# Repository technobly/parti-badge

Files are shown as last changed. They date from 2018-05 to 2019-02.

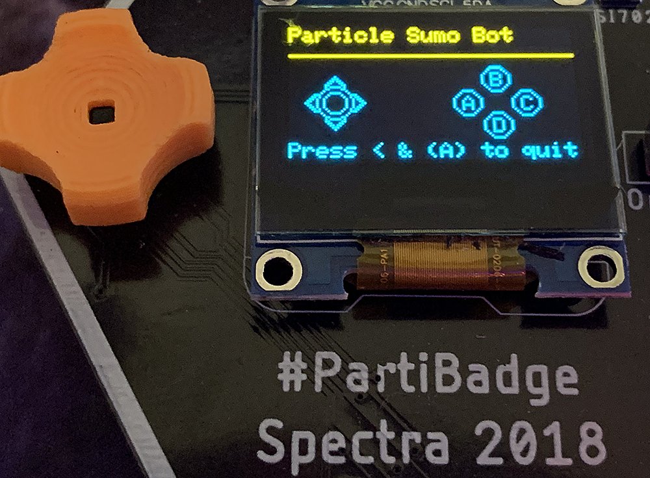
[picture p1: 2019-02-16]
images/sumo-bot-menu.png

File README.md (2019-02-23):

# #PartiBadge Sumo Bot Edition

- Fixed Particle Logo
- Sped up refresh rate of display by 400%
- Sped up boot time with SEMI_AUTOMATIC mode (runs setup() before connected to Particle Cloud) and shortened some things
- Added Sumo Bot Menu
    - Added RC Controller for [Particle Mesh Sumo Bot](https://github.com/technobly/particle-mesh-sumo-bot)
        - Try driving with the joystick and turning at the same time with buttons for smooth figure 8's!
    - Added Logo Turtle OS control system
        - Enter a string of commands `F` `B` `L` `R` and press `>` to send to the Sumo Bot.
        - Use `^` and `v` to adjust the default Command Delay of 500 ms (100 ~ 1000 ms).
- Left rest of PartiBadge functionality in-tact

## Local Compile

```
$ git checkout v0.9.0
$ cd firmware/main
// enter DFU mode
firmware/main $ make clean all -s APPDIR=~/code/debugging/technobly/parti-badge/firmware PLATFORM=xenon COMPILE_LTO=n program-dfu
```



(original README.md follows)

---

# #PartiBadge

The #PartiBadge is a Wi-Fi connected, full-featured, Particle-powered conference badge. Because who want to wear a piece of plastic around their neck when they can wear a PCB?

The #PartiBadge was designed by the Particle team and is currently used as an interactive learning platform for conferences and other developer events.

For workshop hands-on labs and other details, click [here](https://part.cl/workshop).

The hardware folder contains Eagle design files for iterations of the badge hardware. Since the original creation of the Electron-based PartiBadge in the Spring of 2018, there have been two additional major iterations to support the Photon (v2) and Mesh-based hardware (v3).

The firmware folder contains firmware for the latest version of the badge, currently v3.

The finished badge includes:

1.  A 1" OLED Screen
2.  An SMD Piezo buzzer
3.  A SPDT Switch
4.  A 5-way joystick
5.  An SMD Si7021 temperature and Humidity sensor
6.  4 Tactile LED Buttons in Red, Blue, Green and Yellow/Orange
7.  An I2C-Compatible breakout for #BadgeLife add-ons

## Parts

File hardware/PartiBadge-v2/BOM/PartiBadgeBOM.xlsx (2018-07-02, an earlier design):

Part Desc | Footprint names | Reference Part # | Ordered From | Per Badge Cost | # Needed for Badge
SMD 4.7K OHM 1% 1/10W 1206 Resistor | R10 |  | Digi-Key |  | 100
SMD 2.2k OHM 1% 1/16W 1206 Resistor | R5, R6 |  | Digi-Key |  | 200
SMD 200 OHM 5% 1/4W 0805 Resistor | R7 |  | Digi-Key |  | 100
SMD 100 OHM 0.1% 1/4W 1206 | R9 |  | Digi-Key |  | 100
SMD 200 OHM 0.1% 1/4W 1206 | R1, R3, R4 |  | Digi-Key |  | 300
SMD 33 OHM 0.5% 1W 1206 | R2 |  | Digi-Key |  | 100
0.1uF 25V 0603 Ceramic Capacitor | C1 |  | Digi-Key |  | 100
4.7UF 10V X7S 0603 Ceramic Capacitor | C2 |  | Digi-Key |  | 100
Silicon Labs SI7021-A20-IM HU/Temp Sensor 3.6V I2C 3% 6DFN | SI7021 | 336-3142-5-ND (https://www.digikey.com/product-detail/en/silicon-labs/SI7021-A20-IM/336-3142-5-ND/5048937) | Digi-Key |  | 100
Murata Electronics AUDIO PIEZO TRANSDUCER 12.5V SMD (PKMCS0909E4000-R1) | PIEZO | 490-9647-1-ND (https://www.digikey.com/product-detail/en/murata-electronics-north-america/PKMCS0909E4000-R1/490-9647-1-ND/4878401) | Digi-Key |  | 100
E-Switch SWITCH SLIDE SPDT 200MA 30V | S5 | EG1903-ND (https://www.digikey.com/product-detail/en/e-switch/EG1218/EG1903-ND/101726) | Digi-Key |  | 100
LED Tactile Button - Green | GREEN | COM-10440 (https://www.sparkfun.com/products/10440) | Sparkfun |  | 100
LED Tactile Button - Orange | YELLOW | COM-10441 (https://www.sparkfun.com/products/10441) | Sparkfun |  | 100
LED Tactile Button - Red | RED | COM-10442 (https://www.sparkfun.com/products/10442) | Sparkfun |  | 100
LED Tactile Button - Blue | BLUE | COM-10443 (https://www.sparkfun.com/products/10443) | Sparkfun |  | 100
5-way Tactile Switch | JOYSTICK | COM-10063 (https://www.sparkfun.com/products/10063) | Sparkfun |  | 100
Vishay Semiconductor TSMP IR Detector | IC2 | TSMP58000-ND (https://www.digikey.com/product-detail/en/vishay-semiconductor-opto-division/TSMP58000/TSMP58000-ND/4073588) | Digi-Key |  | 100
WorldChips 0.96" OLED Display | U$5 | SSD1306 (https://www.aliexpress.com/item/0-96-inch-IIC-Serial-Yellow-Blue-OLED-Display-Module-128X64-I2C-SSD1306-12864-LCD-Screen/32828449458.html) | AliExpress |  | 100
LiiToKala Li-On 3.7v 3400mAh Battery |  | 18650 (https://www.aliexpress.com/item/6PCS-2017-Original-LiitoKala-18650-3400mAh-NCR18650B-3400-battery-3-7V-Li-ion-Rechargebale-battery-PCB/32824482157.html) | AliExpress |  | 100
Keystone Electronics 1042 Battery Clip | U1 | 36-1042-ND (https://www.digikey.com/product-detail/en/keystone-electronics/1042/36-1042-ND/2745668) | Digi-Key |  | 100
Pololu 5V Step-Up Voltage Regulator U3V12F5 | IC1 | 2115 (https://www.pololu.com/product/2115) | Pololu |  | 100
12 Position Female Header | Photon Headers | S6100-ND (https://www.digikey.com/product-detail/en/sullins-connector-solutions/PPTC121LFBN-RC/S6100-ND/807231) | Digi-Key |  | 200
Badge BOM Total

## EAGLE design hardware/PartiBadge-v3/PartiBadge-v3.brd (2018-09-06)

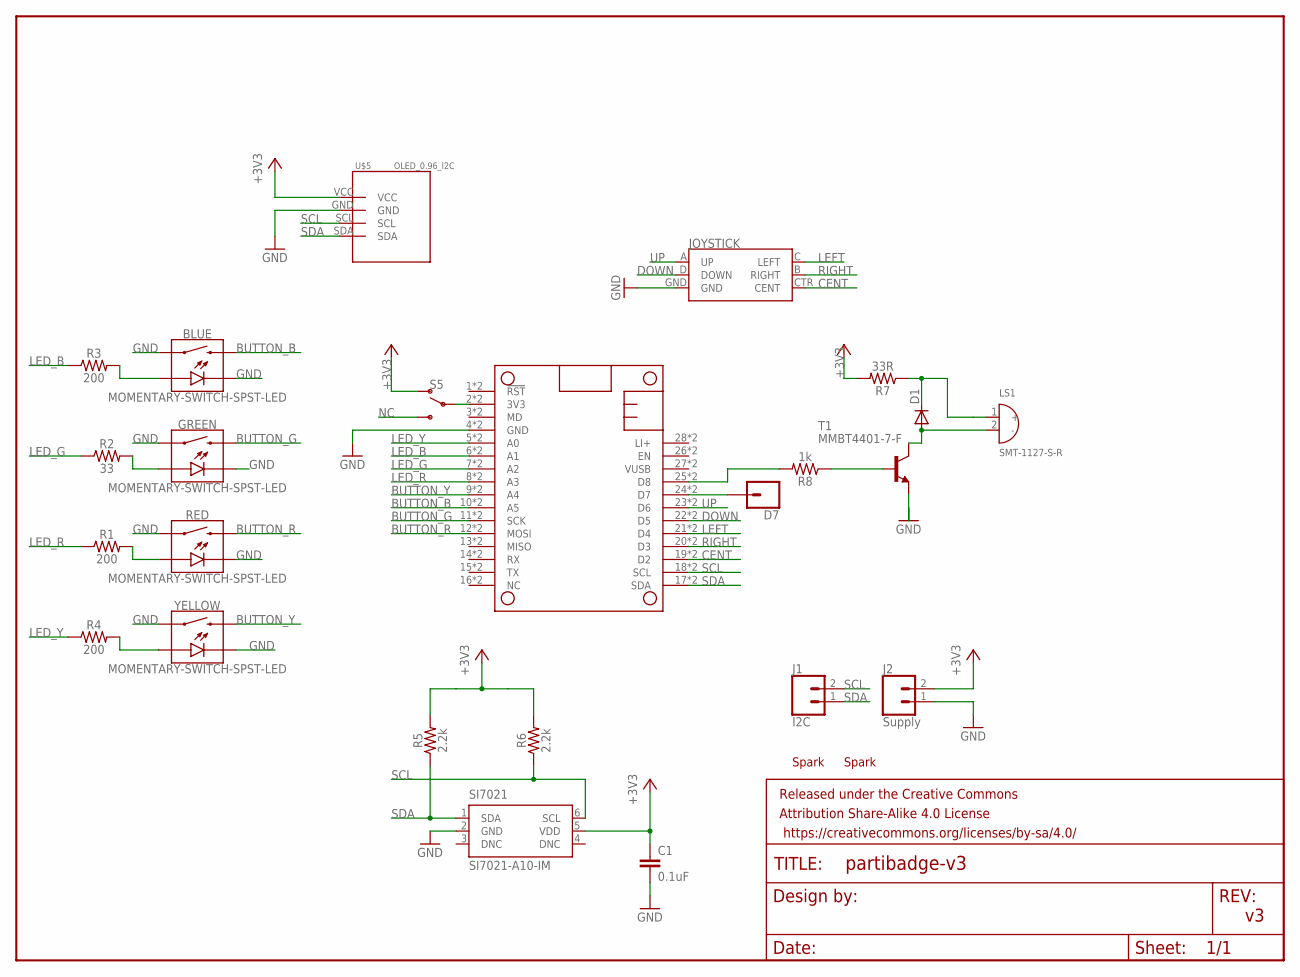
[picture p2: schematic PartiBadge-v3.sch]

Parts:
BLUE: MOMENTARY-SWITCH-SPST-LED; TACTILE_SWITCH_LED_PTH_12MM_KIT
C1: 0.1uF; 0603
D1: DIODE-SOD323-W; SOD323-W
D7: CONN_01; 1X01
GREEN: MOMENTARY-SWITCH-SPST-LED; TACTILE_SWITCH_LED_PTH_12MM_KIT
J1: I2C; 1X02
J2: Supply; 1X02
JOYSTICK: JOYSTICK_MINI
LS1: SMT-1127-S-R; XDCR_SMT-1127-S-R
MS1: PARTICLE_MESH_SMTDUAL; FEATHERWING_SMT2
PARTIFRAME: FRAME-LETTERNO_PACKAGE; DUMMY
R1, R3, R4: 200; 1206
R2: 33; 1206
R5, R6: 2.2k; 0603
R7: 33R; 0603
R8: 1k; 0603
RED: MOMENTARY-SWITCH-SPST-LED; TACTILE_SWITCH_LED_PTH_12MM_KIT
S5: SWITCH-SPDT-PTH-11.6X4.0MM; SWITCH_SPDT_PTH_11.6X4.0MM
SI7021: SI7021-A10-IM; DFN6-3X3
T1: MMBT4401-7-F; SOT23-BEC
U$1, U$2: SPARK_LOGO_WITH_PLANE; SPARK_LOGO_PLUS_PLANE
U$5: OLED_0.96_I2C
YELLOW: MOMENTARY-SWITCH-SPST-LED; TACTILE_SWITCH_LED_PTH_12MM_KIT

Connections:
3V3: MS1.2 (3V3), MS1.2' (3V3), S5.2
+3V3: C1.1, J2.2, R5.2, R6.2, R7.2, S5.1 (O), SI7021.5 (VDD), U$5.VCC
BUTTON_B: BLUE.2, MS1.10 (A5), MS1.10' (A5)
BUTTON_G: GREEN.2, MS1.11 (SCK), MS1.11' (SCK)
BUTTON_R: MS1.12 (MOSI), MS1.12' (MOSI), RED.2
BUTTON_Y: MS1.9 (A4), MS1.9' (A4), YELLOW.2
CENT: JOYSTICK.CTR (CENT), MS1.19 (D2), MS1.19' (D2)
DOWN: JOYSTICK.D (DOWN), MS1.22 (D5), MS1.22' (D5)
GND: BLUE.4 (1), BLUE.C, C1.2, GREEN.4 (1), GREEN.C, J2.1, JOYSTICK.GND, MS1.4 (GND), MS1.4' (GND), RED.4 (1), RED.C, SI7021.2 (GND), T1.E, U$5.GND, YELLOW.4 (1), YELLOW.C
LED_B: MS1.6 (A1), MS1.6' (A1), R3.1
LED_G: MS1.7 (A2), MS1.7' (A2), R2.1
LED_R: MS1.8 (A3), MS1.8' (A3), R1.1
LED_Y: MS1.5 (A0), MS1.5' (A0), R4.1
LEFT: JOYSTICK.C (LEFT), MS1.21 (D4), MS1.21' (D4)
unnamed: D7.1, MS1.24 (D7), MS1.24' (D7)
unnamed: MS1.25 (D8), MS1.25' (D8), R8.2
unnamed: R1.2, RED.A
unnamed: R8.1, T1.B
unnamed: GREEN.A, R2.2
unnamed: BLUE.A, R3.2
unnamed: R4.2, YELLOW.A
unnamed: D1.A, LS1.2 (-), T1.C
unnamed: D1.C, LS1.1 (+), R7.1
NC: S5.3 (S)
RIGHT: JOYSTICK.B (RIGHT), MS1.20 (D3), MS1.20' (D3)
SCL: J1.2, MS1.18 (SCL), MS1.18' (SCL), R6.1, SI7021.6 (SCL), U$5.SCL
SDA: J1.1, MS1.17 (SDA), MS1.17' (SDA), R5.1, SI7021.1 (SDA), U$5.SDA
UP: JOYSTICK.A (UP), MS1.23 (D6), MS1.23' (D6)

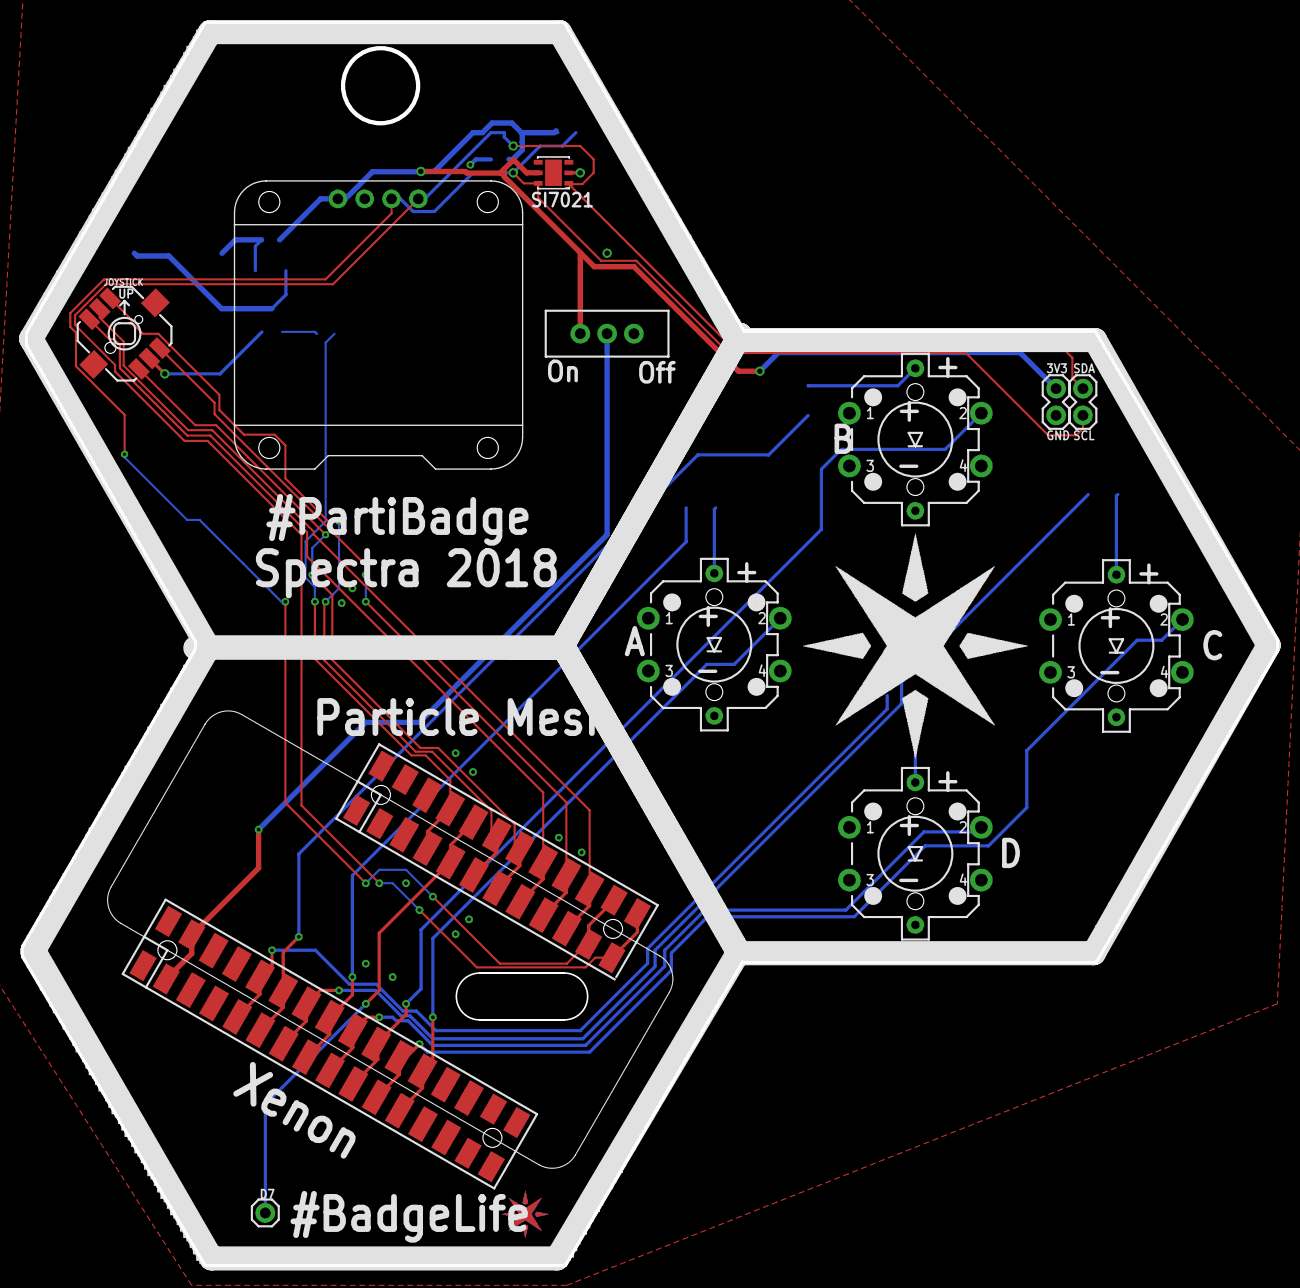
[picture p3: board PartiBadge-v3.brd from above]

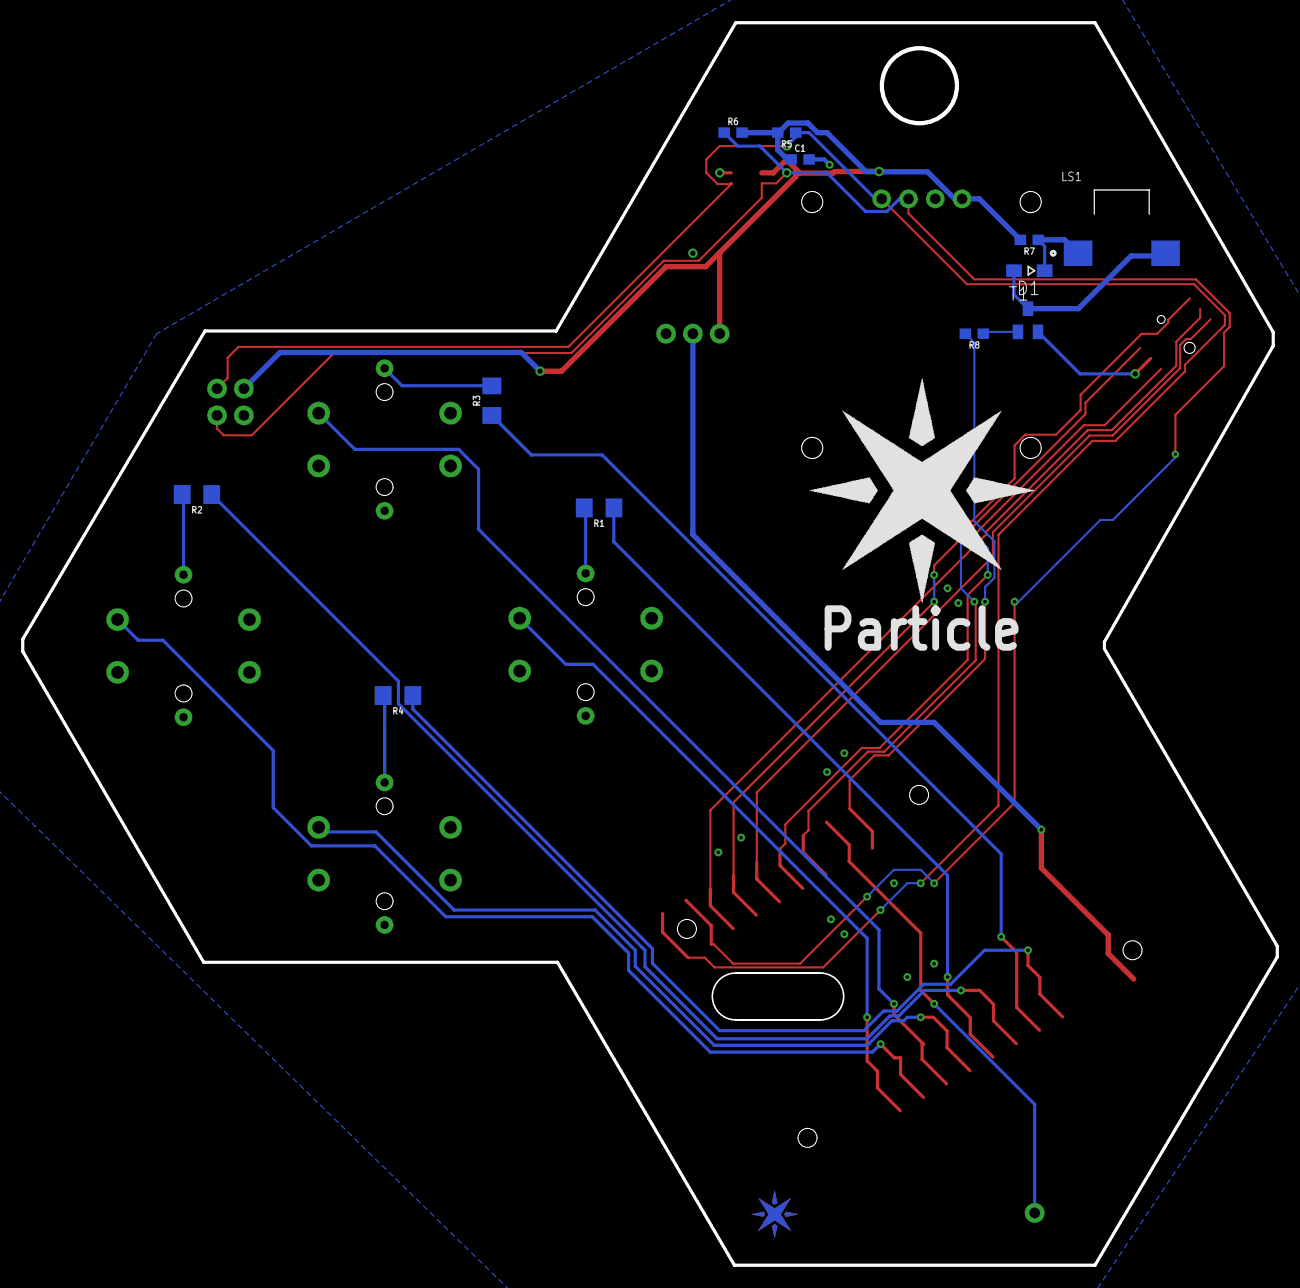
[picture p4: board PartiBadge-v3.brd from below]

Board: 4 copper layers, 118.9 x 117.7 mm, 30 parts (15 on the bottom side), 27 nets.

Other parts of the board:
U$3: MESH#1PX#SVG
U$4, U$6: SPARK-LOGO

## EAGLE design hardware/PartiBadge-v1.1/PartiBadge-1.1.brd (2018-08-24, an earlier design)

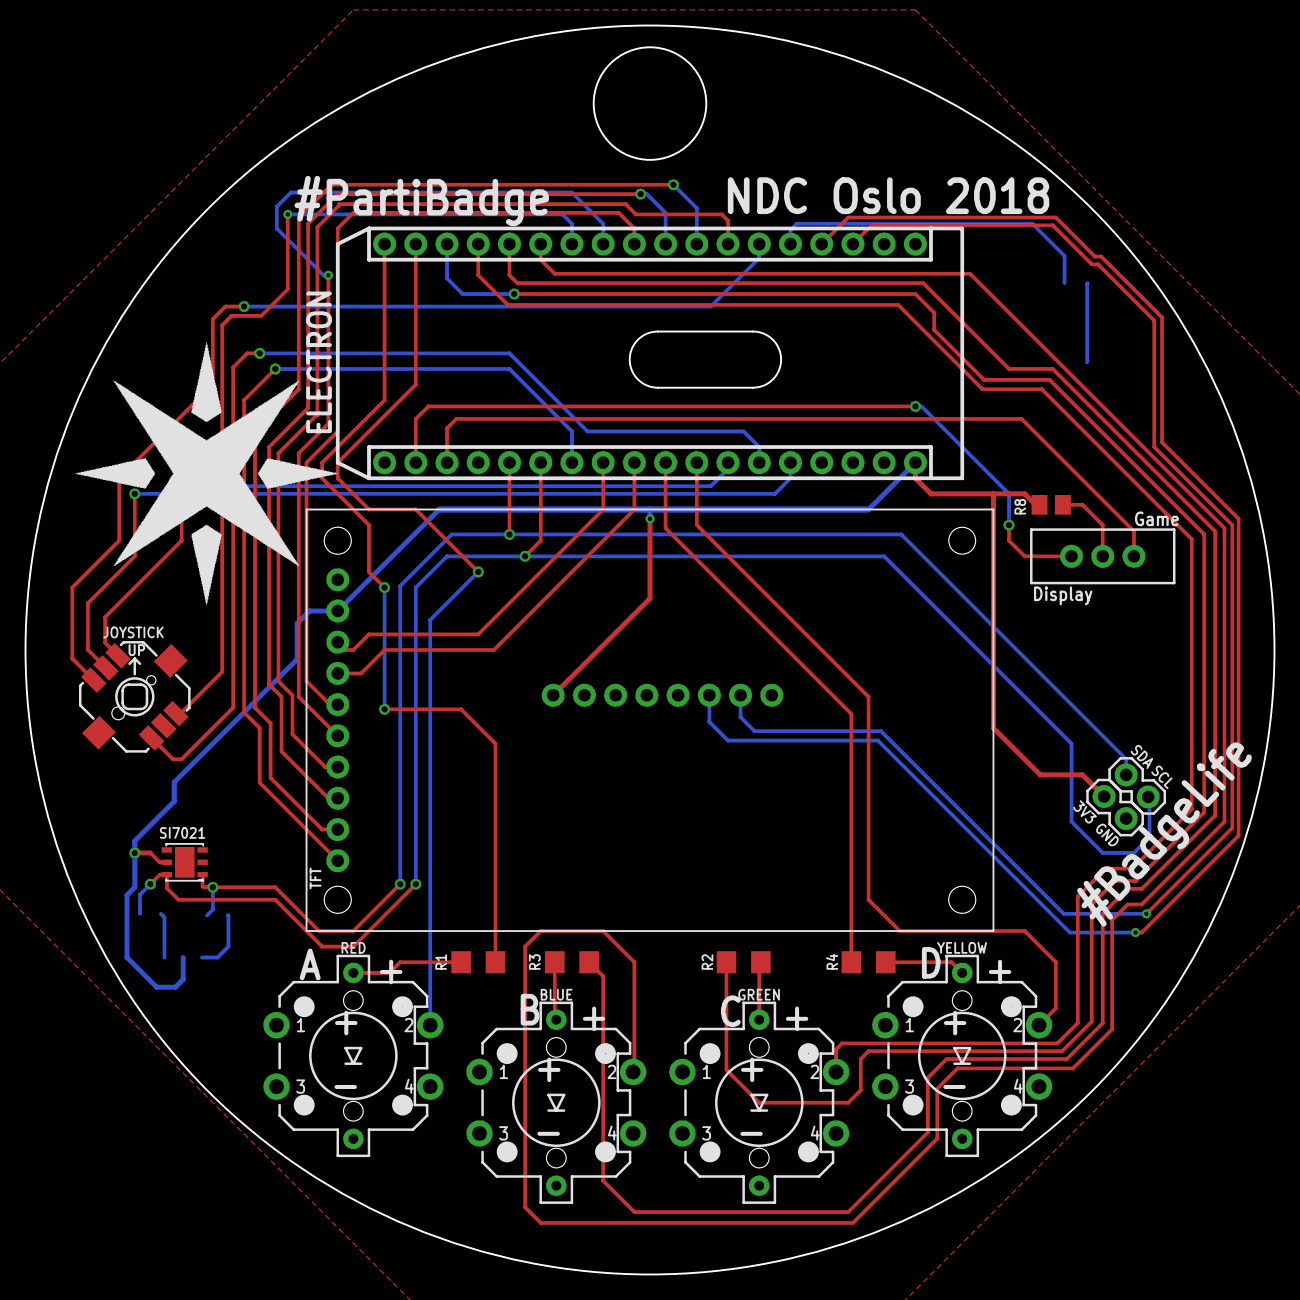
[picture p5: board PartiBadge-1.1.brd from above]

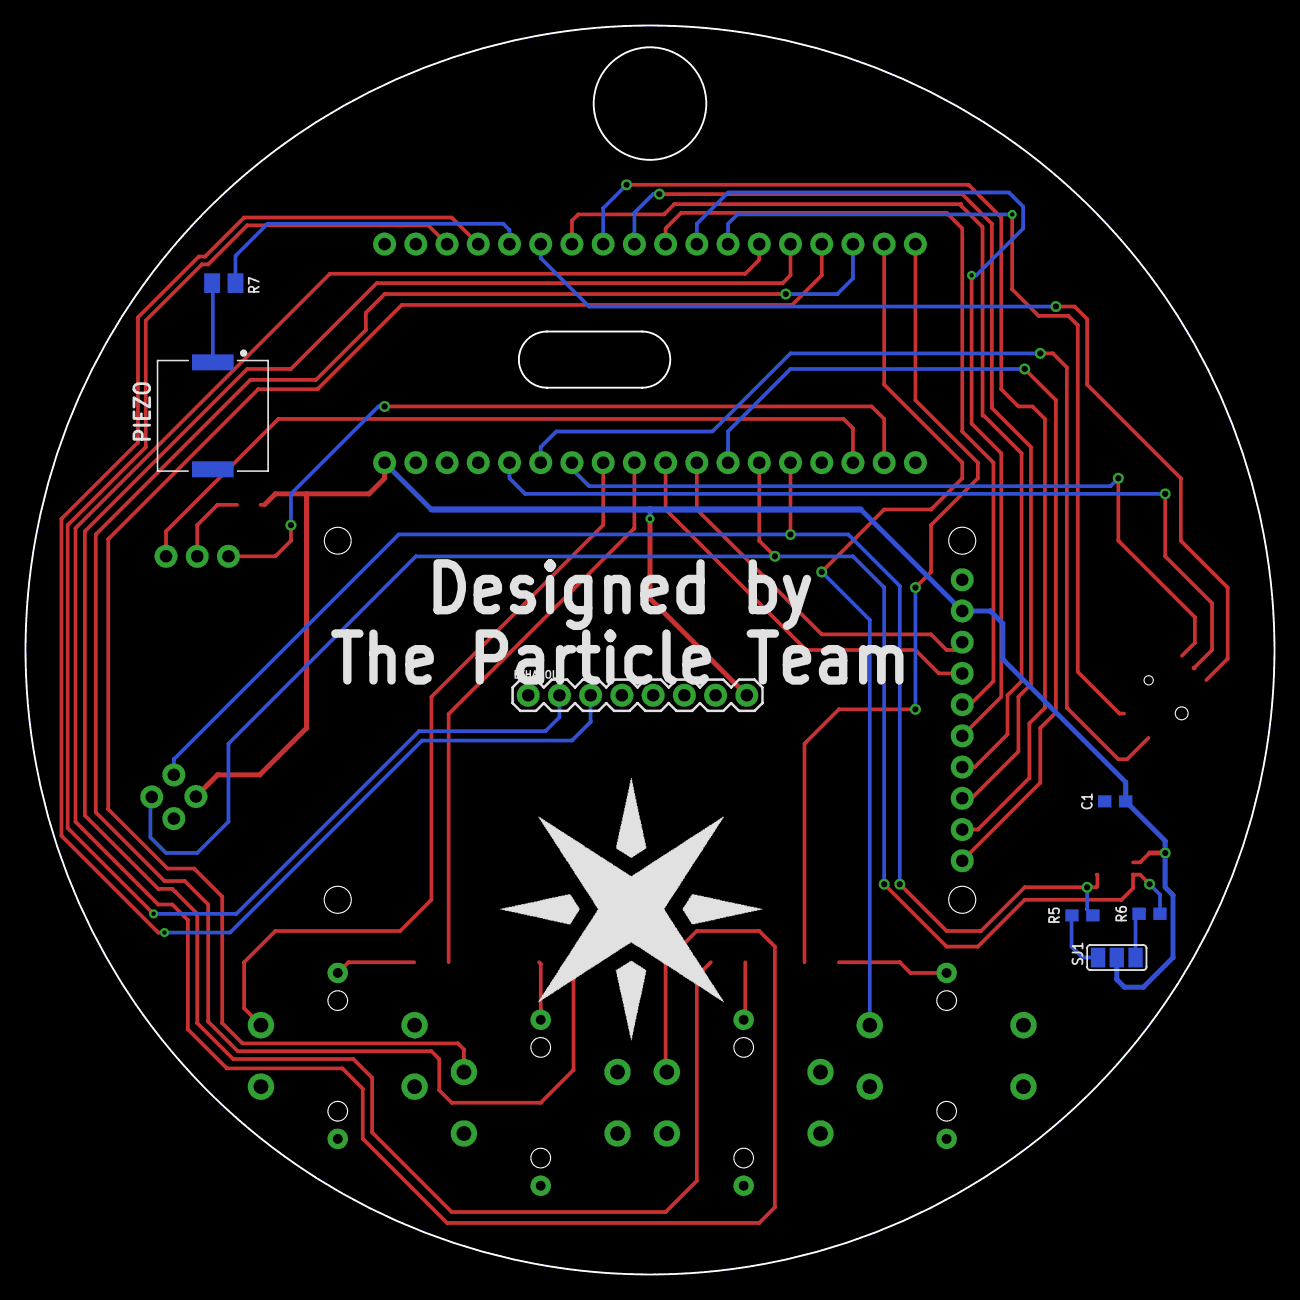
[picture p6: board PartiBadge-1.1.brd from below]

Board: 4 copper layers, 101.6 x 101.6 mm, 28 parts (8 on the bottom side), 38 nets.

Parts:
BLUE: MOMENTARY-SWITCH-SPST-LED; TACTILE_SWITCH_LED_PTH_12MM_KIT
C1: 0.1uF; 0603
DRILEGEND: DRILEGEND
ELECTRON: ELECTRON_WITH_HEADERS; ELECTRON
ETHANOL: 1X08
GREEN: MOMENTARY-SWITCH-SPST-LED; TACTILE_SWITCH_LED_PTH_12MM_KIT
J1: I2C; 1X02
J2: Supply; 1X02
JOYSTICK: JOYSTICK_MINI
PARTIFRAME: FRAME-LETTERNO_PACKAGE; DUMMY
PIEZO: PKMCS0909E4000-R1; XDCR_PKMCS0909E4000-R1
R1, R2, R3, R4: 200; 1206
R5, R6: 4.7k; 0603
R7, R8: 100; M0805
RED: MOMENTARY-SWITCH-SPST-LED; TACTILE_SWITCH_LED_PTH_12MM_KIT
S5: SWITCH_SPDT_PTH_11.6X4.0MM
SI7021: SI7021-A10-IM; DFN6-3X3
SJ1: SJ_2
TFT: 1X10_NO_SILK
U$1, U$2: SPARK#PNG
U$3: FRAME_A_L
YELLOW: MOMENTARY-SWITCH-SPST-LED; TACTILE_SWITCH_LED_PTH_12MM_KIT

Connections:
3V3: C1.1, ELECTRON.36, ETHANOL.8, J2.2, R8.2, SI7021.5, SJ1.2, TFT.9
BUTTON_YELLOW: ELECTRON.29, YELLOW.2
CENT: ELECTRON.32, JOYSTICK.CTR
DOWN: ELECTRON.31, JOYSTICK.D
ELECTRON_RX: ELECTRON.4, ETHANOL.3
ELECTRON_TX: ELECTRON.3, ETHANOL.2
GND: BLUE.4, BLUE.C, C1.2, ELECTRON.2, ELECTRON.33, ETHANOL.6, GREEN.4, GREEN.C, J2.1, JOYSTICK.GND, PIEZO.2, RED.4, RED.C, SI7021.2, TFT.10, YELLOW.4, YELLOW.C
LED_BLUE: ELECTRON.14, R3.1
LED_GREEN: ELECTRON.16, R2.1
LED_RED: ELECTRON.18, R1.1
LED_YELLOW: ELECTRON.28, R4.1
LEFT: ELECTRON.6, JOYSTICK.C
unnamed: ELECTRON.5, R7.2
unnamed: ELECTRON.20, S5.1
unnamed: ELECTRON.21, S5.3
unnamed: R1.2, RED.A
unnamed: ELECTRON.17, RED.2
unnamed: ELECTRON.15, GREEN.2
unnamed: GREEN.A, R2.2
unnamed: BLUE.A, R3.2
unnamed: BLUE.2, ELECTRON.13
unnamed: R4.2, YELLOW.A
unnamed: R5.2, SJ1.3
unnamed: R6.2, SJ1.1
unnamed: PIEZO.1, R7.1
unnamed: R8.1, S5.2
RIGHT: ELECTRON.12, JOYSTICK.B
SCL: ELECTRON.24, J1.2, R6.1, SI7021.6
SDA: ELECTRON.23, J1.1, R5.1, SI7021.1
SD_CS: ELECTRON.10, TFT.6
SPI_DC: ELECTRON.27, TFT.7
SPI_MISO: ELECTRON.8, TFT.2
SPI_MOSI: ELECTRON.7, TFT.4
SPI_SCK: ELECTRON.9, TFT.3
TFT_CS: ELECTRON.11, TFT.5
TFT_LITE: ELECTRON.25, TFT.1
TFT_RST: ELECTRON.26, TFT.8
UP: ELECTRON.30, JOYSTICK.A

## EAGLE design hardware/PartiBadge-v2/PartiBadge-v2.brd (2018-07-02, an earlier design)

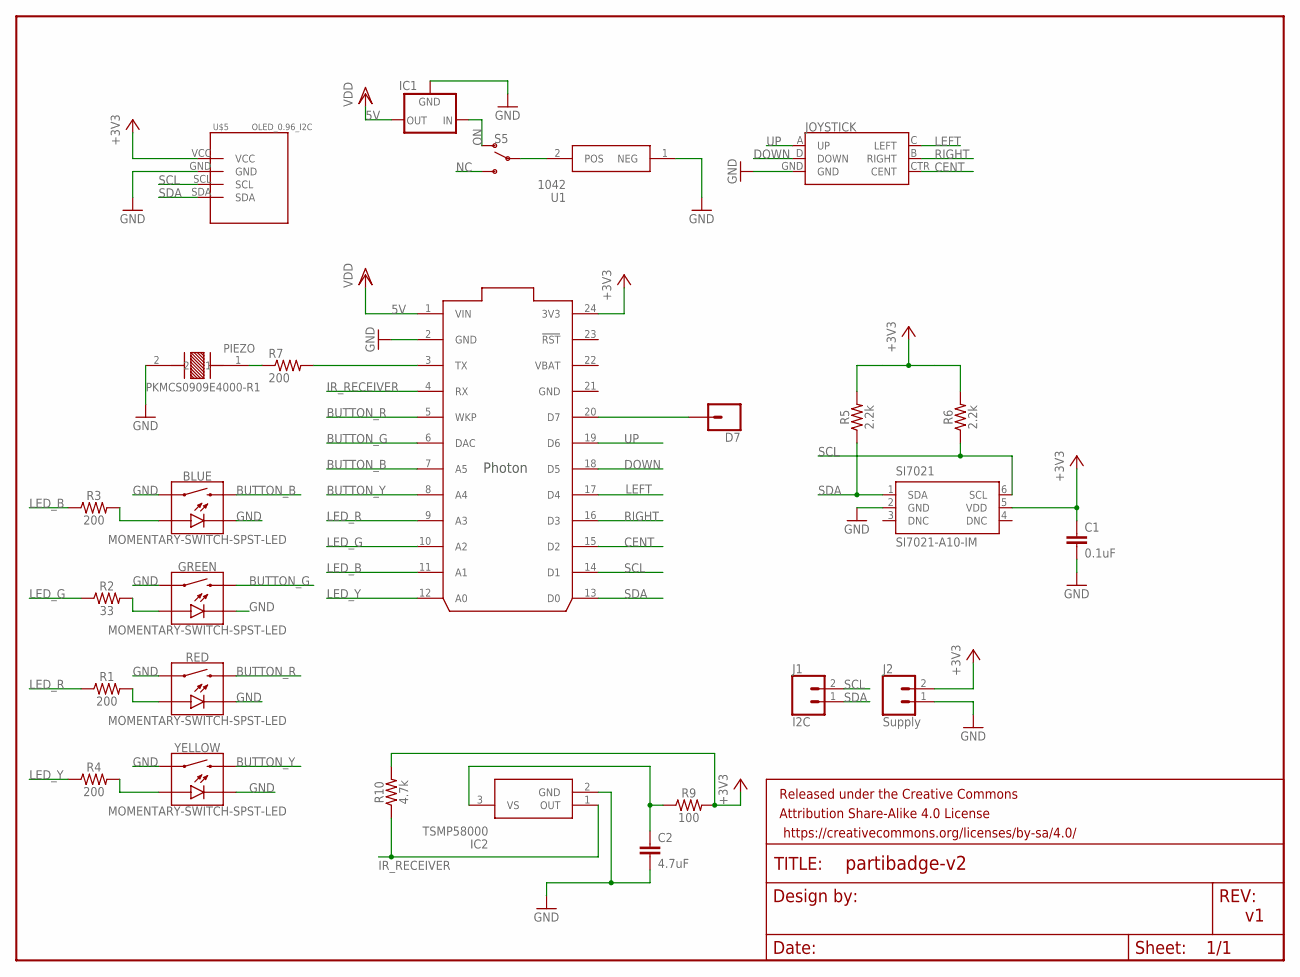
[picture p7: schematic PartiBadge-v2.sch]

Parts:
BLUE: MOMENTARY-SWITCH-SPST-LED; TACTILE_SWITCH_LED_PTH_12MM_KIT
C1: 0.1uF; 0603
C2: 4.7uF; 0603
D7: CONN_01; 1X01
GREEN: MOMENTARY-SWITCH-SPST-LED; TACTILE_SWITCH_LED_PTH_12MM_KIT
IC1: 78XXS
IC2: TSMP58000
J1: I2C; 1X02
J2: Supply; 1X02
JOYSTICK: JOYSTICK_MINI
PARTIFRAME: FRAME-LETTERNO_PACKAGE; DUMMY
PHOTON: PHOTON_WITH_HEADERS; PHOTON
PIEZO: PKMCS0909E4000-R1; XDCR_PKMCS0909E4000-R1
R1, R3, R4: 200; 1206
R2: 33; 1206
R5, R6: 2.2k; 0603
R7: 200; M0805
R9: 100; 1206
R10: 4.7k; 1206
RED: MOMENTARY-SWITCH-SPST-LED; TACTILE_SWITCH_LED_PTH_12MM_KIT
S5: SWITCH-SPDT-PTH-11.6X4.0MM; SWITCH_SPDT_PTH_11.6X4.0MM
SI7021: SI7021-A10-IM; DFN6-3X3
U1: 1042; KEYSTONE-1042
U$5: OLED_0.96_I2C
YELLOW: MOMENTARY-SWITCH-SPST-LED; TACTILE_SWITCH_LED_PTH_12MM_KIT

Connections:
5V: IC1.OUT, PHOTON.1 (VIN)
+3V3: C1.1, J2.2, PHOTON.24 (3V3), R5.2, R6.2, R9.2, R10.2, SI7021.5 (VDD), U$5.VCC
BATT: S5.2, U1.2 (POS)
BUTTON_B: BLUE.2, PHOTON.7 (A5)
BUTTON_G: GREEN.2, PHOTON.6 (DAC)
BUTTON_R: PHOTON.5 (WKP), RED.2
BUTTON_Y: PHOTON.8 (A4), YELLOW.2
CENT: JOYSTICK.CTR (CENT), PHOTON.15 (D2)
D7: D7.1, PHOTON.20 (D7)
DOWN: JOYSTICK.D (DOWN), PHOTON.18 (D5)
GND: BLUE.4 (1), BLUE.C, C1.2, C2.2, GREEN.4 (1), GREEN.C, IC1.GND, IC2.2 (GND), J2.1, JOYSTICK.GND, PHOTON.2 (GND), PHOTON.21 (GND), PIEZO.2, RED.4 (1), RED.C, SI7021.2 (GND), U1.1 (NEG), U$5.GND, YELLOW.4 (1), YELLOW.C
IR_RECEIVER: IC2.1 (OUT), PHOTON.4 (RX), R10.1
LED_B: PHOTON.11 (A1), R3.1
LED_G: PHOTON.10 (A2), R2.1
LED_R: PHOTON.9 (A3), R1.1
LED_Y: PHOTON.12 (A0), R4.1
LEFT: JOYSTICK.C (LEFT), PHOTON.17 (D4)
unnamed: PHOTON.3 (TX), R7.2
unnamed: R1.2, RED.A
unnamed: GREEN.A, R2.2
unnamed: BLUE.A, R3.2
unnamed: C2.1, IC2.3 (VS), R9.1
unnamed: R4.2, YELLOW.A
unnamed: PIEZO.1, R7.1
NC: S5.3 (S)
ON: IC1.IN, S5.1 (O)
RIGHT: JOYSTICK.B (RIGHT), PHOTON.16 (D3)
SCL: J1.2, PHOTON.14 (D1), R6.1, SI7021.6 (SCL), U$5.SCL
SDA: J1.1, PHOTON.13 (D0), R5.1, SI7021.1 (SDA), U$5.SDA
UP: JOYSTICK.A (UP), PHOTON.19 (D6)
VBAT: PHOTON.22 (VBAT)

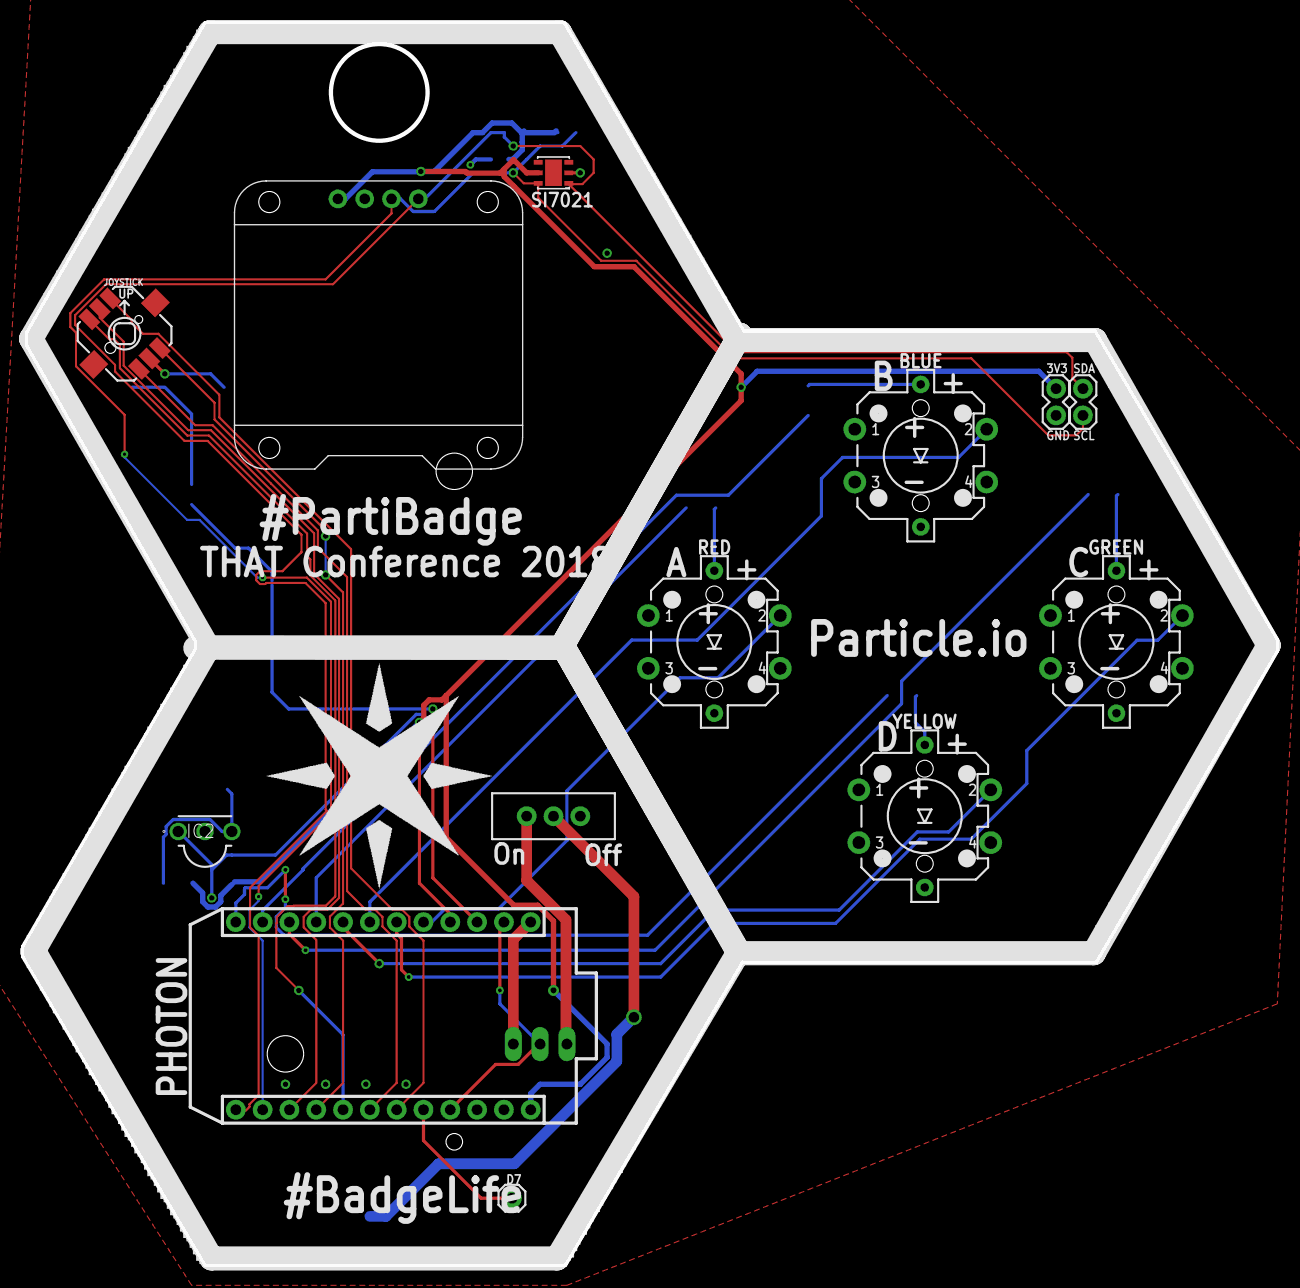
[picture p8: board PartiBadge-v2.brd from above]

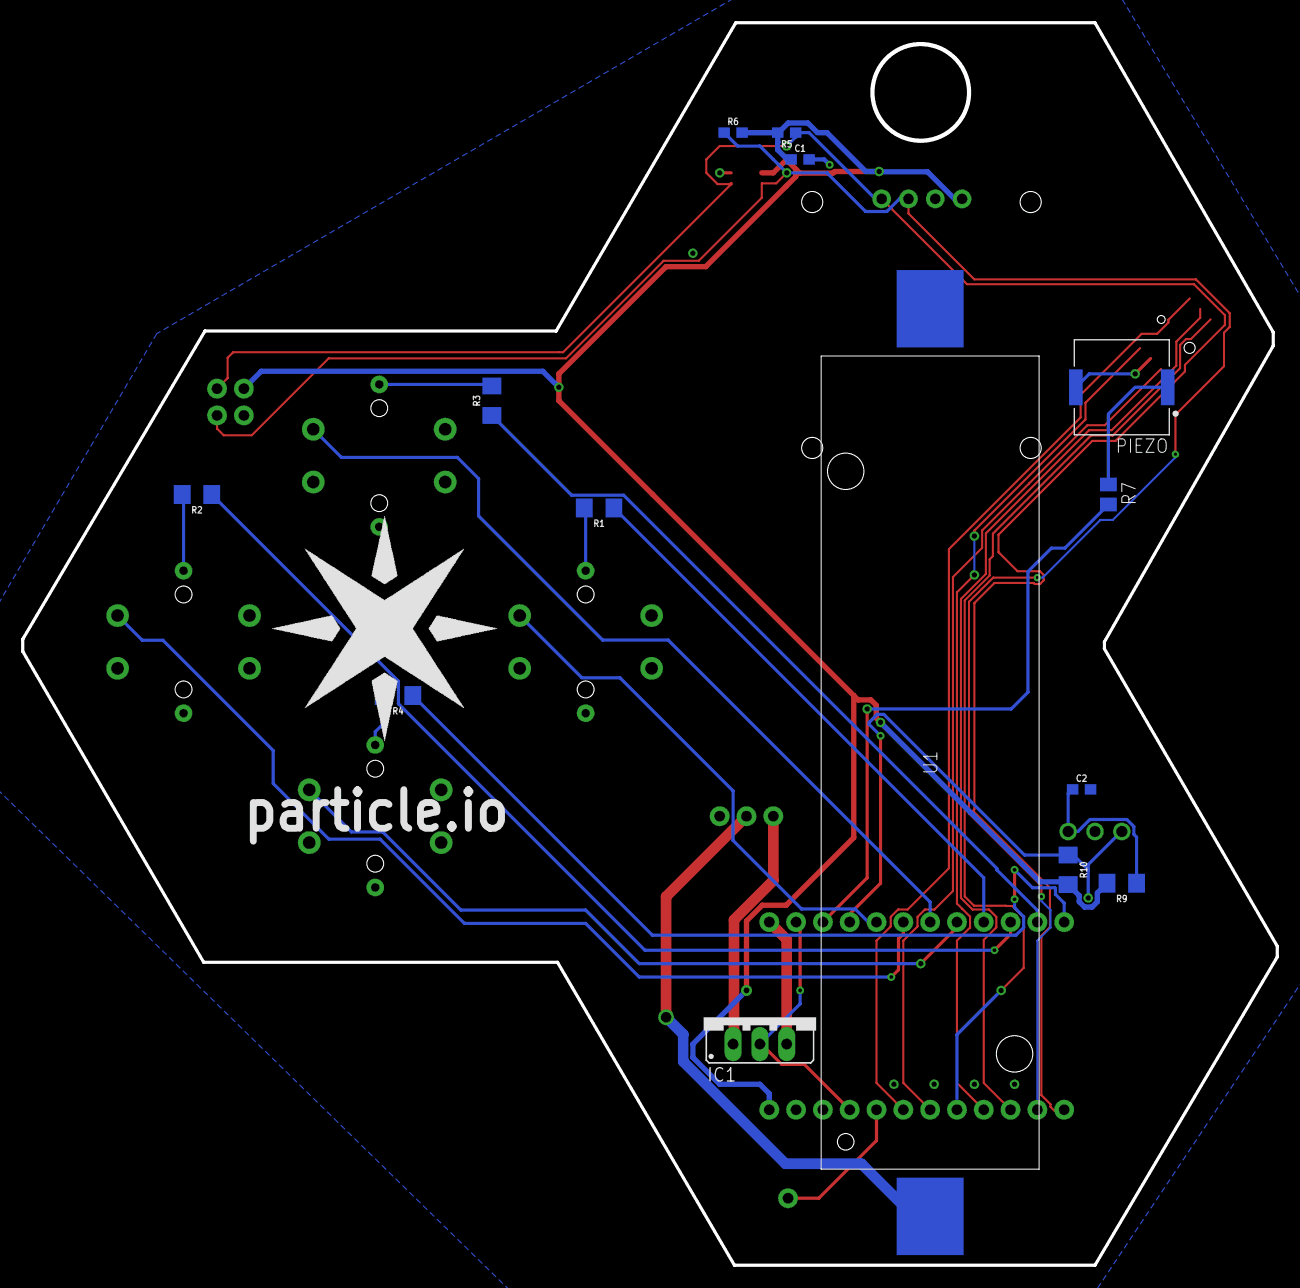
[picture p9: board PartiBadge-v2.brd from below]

Board: 4 copper layers, 118.9 x 117.7 mm, 31 parts (16 on the bottom side), 29 nets.

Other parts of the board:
U$1, U$4: SPARK-LOGO
U$3: MESH#1PX#SVG

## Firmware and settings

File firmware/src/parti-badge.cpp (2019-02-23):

/*
 *      Copyright 2018 Particle Industries, Inc.
 *
 *      Licensed under the Apache License, Version 2.0 (the "License");
 *      you may not use this file except in compliance with the License.
 *      You may obtain a copy of the License at
 *
 *      http://www.apache.org/licenses/LICENSE-2.0
 *
 *      Unless required by applicable law or agreed to in writing, software
 *      distributed under the License is distributed on an "AS IS" BASIS,
 *      WITHOUT WARRANTIES OR CONDITIONS OF ANY KIND, either express or implied.
 *      See the License for the specific language governing permissions and
 *      limitations under the License.
 */
/*
 *      Project: #PartiBadge, 2018 THAT Conference Edition
 *
 *      Description:
 *          This is the firmware for a custom, Photon-based badge PCB that includes:
 *              1. A 1" OLED Screen
 *              2. An SMD Piezo buzzer
 *              3. A SPDT Switch
 *              4. A 5-way joystick
 *              5. An SMD Si7021 temperature and Humidity sensor
 *              6. 4 Tactile LED Buttons in Red, Blue, Green and Yellow/Orange
 *              7. An I2C-Compatible breakout for #BadgeLife add-ons
 *              8. An IR Receiver on the Photon TX pin
 *
 */

#include "Particle.h"

// Display includes
#include "Adafruit_GFX.h"
#include "Adafruit_SSD1306.h"

// Menu System include
#include "mainmenu.h"
#include "qMenuSystem.h"

#include "macros.h" // #define pin assignments and other general macros

// Interrupts
#include "interrupts/interrupts.h"

// Sub-system includes
#include "inputs/inputs.h"
#include "display/display.h"
#include "games/games.h"
#include "games/simon.h"
#include "leds/leds.h"
#include "music/music.h"
#include "keylogger/keylogger.h"
#include "sensors/sensors.h"
#include "animations/animations.h"
#include "mesh/mesh.h"
#include "udp/udp.h"
#include "rc-sumo/rc-sumo.h"
#include "logo-turtle-os/logo-turtle-os.h"

#include "music/roll.h"
#include "WearerInfo/WearerInfo.h"
#include "music/xmassongs.h"

#include "Adafruit_Si7021.h"
#include "events/events.h"

SYSTEM_MODE(SEMI_AUTOMATIC);
SYSTEM_THREAD(ENABLED);

// Init Display
Adafruit_SSD1306 display(RESET);
void resetDisplayBools();

// Menu Init
qMenuSystem menu = qMenuSystem(&display);

String deviceId;
WearerInfo wearerInfo;

// Initialize Si7021 sensor
Adafruit_Si7021 envSensor = Adafruit_Si7021();
int currentTemp;
int currentHumidity;
int currentBatteryReading;

// Timing variables
unsigned long elapsedTime;
unsigned long startTime = 0;
unsigned long previousEnvReading = 0;
unsigned long previousBatteryReading = 0;

// Wearer details
String wearerFirstName;
String wearerLastName;
String wearerTwitter;

// Display variables
extern bool displayingTemp;
extern bool displayingWearerDetails;
extern bool displayingCarousel;
extern bool displayingBattery;
extern bool showingLightAnimation;
bool menuShowing = false;

// Display state management
bool checkingInputs = false;

volatile byte btncounter = 0;
volatile byte btnid = 0;
byte appmode = 0;

int updateFirstNameHandler(String data);
int updateLastNameHandler(String data);
int updateTwitterHandler(String data);
int checkTempHandler(String data);
void cloudInit();
void initWearerDetails();

void setup()
{
  Serial.begin();

  // setup Mesh
  meshSetup();

  resetDisplayBools();

  // Get the current deviceId
  deviceId = System.deviceID();

  // Initialize Temp and Humidity sensor
  while (!envSensor.begin())
    ;

  // Init OLED
  display.begin(SSD1306_SWITCHCAPVCC, 0x3C);

  // Show Particle Splashscreen
  showSplashscreen(1000);

  // Show the title screen
  showTitle();

  // Set up cloud variables and functions
  cloudInit();

  // Set up mesh subscribe handlers
  setupMeshEvents();

  // Set the Piezo buzzer as an output
  pinMode(BUZZER_PIN, OUTPUT);

  // Init the LED and Joystick Buttons
  initInputDebouncers();

  // Set up Interrupts
  setupJoystickInterrupts();

  // Get an initial temp and humidity reading
  getTempAndHumidity();

  // Get an Initial Battery Reading
  getBatteryReading();

  //Init Tactile LED Buttons
  initLEDButtons();

  // Play a startup sound on the Piezo
  // playStartup(BUZZER_PIN, false);

  // Connect to the Particle device cloud
  Particle.connect();

  // Fetch badge wearer details from EEPROM
  initWearerDetails();

  // Scroll the title text on the screen
  display.startscrollleft(0x00, 0x0F);
}

void loop()
{
  unsigned long currentMillis = millis();
  int clickedItem = 0;

  // Display MENU by button press if not showing already
  if (menuShowing == false)
  {
    redButtonADebouncer.update();
    blueButtonBDebouncer.update();
    greenButtonCDebouncer.update();
    yellowButtonDDebouncer.update();
    joystickCenterDebouncer.update();

    if (redButtonADebouncer.read() == LOW ||
        blueButtonBDebouncer.read() == LOW ||
        greenButtonCDebouncer.read() == LOW ||
        yellowButtonDDebouncer.read() == LOW ||
        joystickCenterDebouncer.read() == LOW)
    {
      menuShowing = true;

      clearScreen();
      menu.InitMenu(mnuRoot, cntRoot, 1);
    }
  }

  if (btncounter > 0 && menuShowing)
  {
    switch (btnid)
    {
    case 1:
    case 5:
      clickedItem = menu.ProcessMenu(ACTION_SELECT);
      btncounter--;
      break;
    case 2:
      menu.ProcessMenu(ACTION_DOWN);
      btncounter--;
      break;
    case 3:
      menu.ProcessMenu(ACTION_UP);
      btncounter--;
      break;
    case 4:
      clickedItem = menu.ProcessMenu(ACTION_BACK);
      btncounter--;
      break;
    }
  }

  if (clickedItem > 0 && menuShowing)
  {
    clearScreen();

    if (menu.CurrentMenu == mnuRoot)
    {
      switch (clickedItem)
      {
      case 1:
        menu.InitMenu((const char **)mnuMode, cntMode, 1);
        break;
      case 2:
        menu.InitMenu((const char **)mnuDisplay, cntDisplay, 1);
        break;
      case 3:
        menu.InitMenu((const char **)mnuMesh, cntMesh, 1);
        break;
      case 4:
        menu.InitMenu((const char **)mnuSensors, cntSensors, 1);
        break;
      case 5:
        menu.InitMenu((const char **)mnuMusic, cntMusic, 1);
        break;
      case 6:
        menu.InitMenu((const char **)mnuGames, cntGames, 1);
        break;
      case 7:
        menu.InitMenu((const char **)mnuGraphics, cntGraphics, 1);
        break;
      case 8:
        menu.InitMenu((const char **)mnuAnimations, cntAnimations, 1);
        break;
      case 9:
        menu.InitMenu((const char **)mnuBlinky, cntBlinky, 1);
        break;
      case 10:
        displayCredits();
        break;
      }
    }
    // Logic for sub menus
    else if (menu.CurrentMenu == mnuMode)
    {
      switch (clickedItem)
      {
      case 1:
        updateRcSumo();
        break;
      case 2:
        updateLogoTurtleOS();
        break;
      case 3:
        menu.InitMenu(mnuRoot, cntRoot, 1);
        break;
      }
    }
    else if (menu.CurrentMenu == mnuDisplay)
    {
      switch (clickedItem)
      {
      case 1:
        showTitle();
        display.startscrollleft(0x00, 0x0F);
        break;
      case 2:
        displayWearerDetails();
        break;
      case 3:
        displayTwitterHandle();
        break;
      case 4:
        showTempAndHumidity();
        break;
      case 5:
        displayCarousel();
        break;
      case 6:
        menu.InitMenu(mnuRoot, cntRoot, 2);
        break;
      }
    }
    else if (menu.CurrentMenu == mnuMesh)
    {
      switch (clickedItem)
      {
      case 1:
        getMeshNetworkInfo();
        break;
      case 2:
        fireHelloPingEvent();
        break;
      case 3:
        fireGatewayPingEvent();
        break;
      case 4:
        fireStartSpookyEvent();
        break;
      case 5:
        fireStopSpookyEvent();
        break;
      case 6:
        menu.InitMenu(mnuRoot, cntRoot, 3);
        break;
      }
    }
    else if (menu.CurrentMenu == mnuSensors)
    {
      switch (clickedItem)
      {
      case 1:
        showTempAndHumidity();
        break;
      case 2:
        showBattery();
        break;
      case 3:
        menu.InitMenu(mnuRoot, cntRoot, 4);
        break;
      }
    }
    else if (menu.CurrentMenu == mnuMusic)
    {
      switch (clickedItem)
      {
      case 1:
        playStartup(BUZZER_PIN, true);
        break;
      case 2:
        playGameOver(BUZZER_PIN, true);
        break;
      case 3:
        playRoll();
        break;
      case 4:
        playBeegees();
        break;
      case 5:
        playJoyToTheWorld();
        break;
      case 6:
        playWeWishYouAMerryXmas();
        break;
      case 7:
        playRudolfTheRedNosedReindeer();
        break;
      case 8:
        playJingleBells();
        break;
      case 9:
        playSilentNight();
        break;
      case 10:
        menu.InitMenu(mnuRoot, cntRoot, 5);
        break;
      }
    }
    else if (menu.CurrentMenu == mnuGames)
    {
      switch (clickedItem)
      {
      case 1:
        etchASketch();
        break;
      case 2:
        snakeGame();
        break;
      case 3:
        initSimon();
        break;
      case 4:
        menu.InitMenu(mnuRoot, cntRoot, 6);
        break;
      }
    }
    else if (menu.CurrentMenu == mnuGraphics)
    {
      switch (clickedItem)
      {
      case 1:
        showSpark();
        break;
      case 2:
        showSpectra();
        break;
      case 3:
        showMesh();
        break;
      case 4:
        showKonami();
        break;
      case 5:
        menu.InitMenu(mnuRoot, cntRoot, 7);
        break;
      }
    }
    else if (menu.CurrentMenu == mnuAnimations)
    {
      switch (clickedItem)
      {
      case 1:
        snowflakes();
        break;
      case 2:
        drawCircles();
        break;
      case 3:
        drawRectangles();
        break;
      case 4:
        drawTriangles();
        break;
      case 5:
        drawRoundedRectangles();
        break;
      case 6:
        scrollText();
        break;
      case 7:
        cycleAnimations();
        break;
      case 8:
        menu.InitMenu(mnuRoot, cntRoot, 8);
        break;
      }
    }
    else if (menu.CurrentMenu == mnuBlinky)
    {
      switch (clickedItem)
      {
      case 1:
        ledChase();
        break;
      case 2:
        ledPulse(true);
        break;
      case 3:
        ledPulseChase();
        break;
      case 4:
        ledRandom();
        break;
      case 5:
        ledSeeSaw();
        break;
      case 6:
        menu.InitMenu(mnuRoot, cntRoot, 9);
        break;
      }
    }
  }
  else if (clickedItem == -1 && menuShowing)
  {
    if (menu.CurrentMenu == mnuRoot)
    { /* In root, do nothing */
    }

    //2nd level menus
    else if (menu.CurrentMenu == mnuMode)
    {
      menu.InitMenu((const char **)mnuRoot, cntRoot, 1);
    }
    else if (menu.CurrentMenu == mnuDisplay)
    {
      menu.InitMenu((const char **)mnuRoot, cntRoot, 2);
    }
    else if (menu.CurrentMenu == mnuMesh)
    {
      menu.InitMenu((const char **)mnuRoot, cntRoot, 3);
    }
    else if (menu.CurrentMenu == mnuSensors)
    {
      menu.InitMenu((const char **)mnuRoot, cntRoot, 4);
    }
    else if (menu.CurrentMenu == mnuMusic)
    {
      menu.InitMenu((const char **)mnuRoot, cntRoot, 5);
    }
    else if (menu.CurrentMenu == mnuGames)
    {
      menu.InitMenu((const char **)mnuRoot, cntRoot, 6);
    }
    else if (menu.CurrentMenu == mnuGraphics)
    {
      menu.InitMenu((const char **)mnuRoot, cntRoot, 7);
    }
    else if (menu.CurrentMenu == mnuAnimations)
    {
      menu.InitMenu((const char **)mnuRoot, cntRoot, 8);
    }
    else if (menu.CurrentMenu == mnuBlinky)
    {
      menu.InitMenu((const char **)mnuRoot, cntRoot, 9);
    }
  }

  if (displayingCarousel)
  {
    displayCarousel();
  }

  if (currentMillis - previousBatteryReading > BATT_CHECK_INTERVAL)
  {
    previousBatteryReading = currentMillis;
    getBatteryReading();
  }

  if (currentMillis - previousEnvReading > TEMP_CHECK_INTERVAL)
  {
    previousEnvReading = currentMillis;
    getTempAndHumidity();
  }

  blueButtonBDebouncer.update();
  if (blueButtonBDebouncer.read() == LOW)
  {
    fireTowerSendEvent();
  }

  if (!showingLightAnimation)
  {
    redButtonADebouncer.update();
    if (redButtonADebouncer.read() == LOW)
    {
      analogWrite(RED_LED, 255);
    }
    else
    {
      analogWrite(RED_LED, 0);
    }

    blueButtonBDebouncer.update();
    if (blueButtonBDebouncer.read() == LOW)
    {
      analogWrite(BLUE_LED, 255);
    }
    else
    {
      analogWrite(BLUE_LED, 0);
    }

    greenButtonCDebouncer.update();
    if (greenButtonCDebouncer.read() == LOW)
    {
      analogWrite(GREEN_LED, 255);
    }
    else
    {
      analogWrite(GREEN_LED, 0);
    }

    yellowButtonDDebouncer.update();
    if (yellowButtonDDebouncer.read() == LOW)
    {
      analogWrite(YELLOW_LED, 255);
    }
    else
    {
      analogWrite(YELLOW_LED, 0);
    }
  }
}

// Init our Device Cloud variables and functions
void cloudInit()
{
  Particle.variable("wearerFName", wearerFirstName);
  Particle.variable("wearerLName", wearerLastName);
  Particle.variable("wearerTwttr", wearerTwitter);

  Particle.variable("currentTemp", currentTemp);
  Particle.variable("currentHu", currentHumidity);

  Particle.function("updateFName", updateFirstNameHandler);
  Particle.function("updateLName", updateLastNameHandler);
  Particle.function("updateTwttr", updateTwitterHandler);

  Particle.function("checkTemp", checkTempHandler);

  Particle.subscribe("pulseLed", pulseLEDHandler, MY_DEVICES);
}

// Fetch wearer details from our WearerInfo class
void initWearerDetails()
{
  wearerInfo = WearerInfo();

  if (wearerInfo.isSet())
  {
    wearerFirstName = wearerInfo.getFirstName();
    wearerLastName = wearerInfo.getLastName();
    wearerTwitter = wearerInfo.getTwitter();
  }
}

//Update the first name when called from a cloud function
int updateFirstNameHandler(String data)
{
  wearerFirstName = data;
  wearerInfo.setFirstName(wearerFirstName);

  if (displayingWearerDetails)
  {
    displayWearerDetails();
  }
  return 1;
}

//Update the last name when called from a cloud function
int updateLastNameHandler(String data)
{
  wearerLastName = data;
  wearerInfo.setLastName(wearerLastName);

  if (displayingWearerDetails)
  {
    displayWearerDetails();
  }
  return 1;
}

int updateTwitterHandler(String data)
{
  wearerTwitter = data;
  wearerInfo.setTwitter(wearerTwitter);

  if (displayingWearerDetails)
  {
    displayWearerDetails();
  }
  return 1;
}

// Check the temp and humidity when called from a cloud function
int checkTempHandler(String data)
{
  getTempAndHumidity();

  return 1;
}

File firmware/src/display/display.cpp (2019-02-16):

#include "Adafruit_SSD1306.h"
#include "qMenuSystem.h"

#include "macros.h"
#include "images/spark.h"
#include "images/spectra.h"
#include "images/temp.h"
#include "images/humidity.h"
#include "images/konami.h"
#include "images/mesh.h"
#include "images/battery.h"
#include "display.h"

extern Adafruit_SSD1306 display;
extern qMenuSystem menu;
extern String wearerFirstName;
extern String wearerLastName;
extern String wearerTwitter;
extern bool titleShown;
extern int currentTemp;
extern int currentHumidity;
extern int currentBatteryReading;

bool displayingTemp = false;
bool displayingBattery = false;
bool displayingWearerDetails = false;
bool displayingCarousel = false;
bool showingLightAnimation = false;

// Array of function pointers so we can rotate through each in carousel mode
void (*carouselFuncs[])(void) = {
    showTitle,
    showSpark,
    showTempAndHumidity,
    showSpectra,
    displayWearerDetails};
int funcArraySize = sizeof(carouselFuncs) / sizeof(carouselFuncs[0]);
int currentFunc = 0;
unsigned long prevCarouselRotation;

void displayCarousel()
{
  unsigned long currentMillis = millis();

  if (!displayingCarousel)
  {
    currentFunc = 0;
    prevCarouselRotation = millis();
    carouselFuncs[currentFunc]();
    displayingCarousel = true;
  }
  else if (currentMillis - prevCarouselRotation > CAROUSEL_INTERVAL)
  {
    prevCarouselRotation = currentMillis;
    carouselFuncs[currentFunc]();
    currentFunc++;

    if (currentFunc == funcArraySize)
    {
      currentFunc = 0;
    }
  }
}

// Reset all display-related state booleans
void resetDisplayBools()
{
  displayingTemp = false;
  displayingWearerDetails = false;
  displayingCarousel = false;
  displayingBattery = false;
  showingLightAnimation = false;
}

// Clear the OLED display
void clearScreen()
{
  display.stopscroll();
  display.clearDisplay();
  display.display();
  display.setCursor(0, 0);
  display.setTextWrap(true);
}

int getCenterX(const char text[], int textSize)
{
  int textWidth = strlen(text) * 9 * textSize;

  return 64 - (textWidth / 2);
}

void messageBoxWithArray(const char *textStrings[], int arrayLen, int textSize)
{
  int textHeight = 12;
  int y = textSize == 1 ? 64 / arrayLen : 18;
  clearScreen();
  display.setTextSize(textSize);

  for (int i = 0; i < arrayLen; i++)
  {
    int x = getCenterX(textStrings[i], textSize);

    display.setCursor(x + (15 / textSize) + i, y + textHeight * i * textSize);
    display.println(textStrings[i]);
  }
  display.display();
}

void showSplashscreen(system_tick_t wait)
{
  clearScreen();
  display.drawBitmap(0, 16, sparkLogo, 128, 48, 1);
  display.display();
  delay(wait);
  // clearScreen();
  // display.drawBitmap(0, 0, spectraLogo, 128, 64, 1);
  // display.display();
  // delay(wait);
}

// Display the wearer's first and last name on the display
void displayWearerDetails()
{
  displayingWearerDetails = true;

  int fnameLength = wearerFirstName.length();
  int lnameLength = wearerLastName.length();
  int longestLength = ((fnameLength > lnameLength) ? fnameLength : lnameLength);

  if (fnameLength > 0 || lnameLength > 0)
  {
    clearScreen();
    //put Twitter info up in yellow band area
    if (wearerTwitter.length() > 10)
    {
      display.setTextSize(1);
    }
    if (wearerTwitter.length() > 0)
    {
      display.println(wearerTwitter);
    }

    // setTextSize based on largest of two lengths
    // Display is 128 x 64
    // So if the longest of the two names is longer than 10 characters,
    // set the size to 1
    if (longestLength > 10)
    {
      display.setTextSize(1);
      display.setCursor(0, 20);
    }
    else
    {
      display.setTextSize(2);
      display.setCursor(0, 10);
    }

    display.println();

    if (wearerFirstName.length() > 0)
    {
      display.println(wearerFirstName);
    }
    if (wearerLastName.length() > 0)
    {
      display.println(wearerLastName);
    }

    display.display();
    display.startscrollleft(0x00, 0x0F);
  }
}

void displayTwitterHandle()
{
  displayingWearerDetails = true;

  clearScreen();
  display.setTextSize(2);
  display.setCursor(0, 10);
  display.println();

  if (wearerTwitter.length() > 0)
  {
    display.println(wearerTwitter);
  }

  display.display();
  display.startscrollleft(0x00, 0x0F);
}

// Show the title text on the display
void showTitle()
{
  display.clearDisplay();
  display.setTextWrap(true);
  display.setTextColor(WHITE);
  display.setTextSize(2);

  display.setCursor(1, 18);
  display.println("PartiBadge");
  display.setCursor(0, 35);
  display.println("Sumo Bot");
  display.display();
}

void showBattery()
{
  clearScreen();

  display.setTextSize(1);
  display.setCursor(25, 1);
  display.print("Battery - ");
  display.print((int)currentBatteryReading);
  display.println("%");

  // Show battery image based on reading
  int battX = 28;
  int battY = 23;
  if (currentBatteryReading > 0 && currentBatteryReading <= 20)
  {
    display.drawBitmap(battX, battY, batteryEmptyImage, 72, 32, 1);
  }
  else if (currentBatteryReading > 20 && currentBatteryReading <= 50)
  {
    display.drawBitmap(battX, battY, batteryLowImage, 72, 32, 1);
  }
  else if (currentBatteryReading > 50 && currentBatteryReading <= 90)
  {
    display.drawBitmap(battX, battY, batteryMediumImage, 72, 32, 1);
  }
  else
  {
    display.drawBitmap(battX, battY, batteryFullImage, 72, 32, 1);
  }

  display.display();
  display.setTextSize(1);

  displayingBattery = true;
}

// Show the temperature and humidity on the display
void showTempAndHumidity()
{
  clearScreen();

  display.drawBitmap(7, 18, tempImage, 16, 43, 1);
  display.setTextSize(1);
  display.setCursor(52, 16);
  display.println("Temp");
  display.setTextSize(2);
  display.setCursor(48, 25);
  display.print((int)currentTemp);
  display.println("f");
  display.setTextSize(1);
  display.setCursor(42, 42);
  display.println("Humidity");
  display.setTextSize(2);
  display.setCursor(48, 50);
  display.print((int)currentHumidity);
  display.println("%");
  display.drawBitmap(105, 28, humidityImage, 20, 27, 1);
  display.display();
  display.setTextSize(1);

  displayingTemp = true;
}

void showSpark()
{
  clearScreen();
  display.drawBitmap(0, 16, sparkLogo, 128, 48, 1);
  display.display();
  display.startscrollleft(0x00, 0x0F);
}

void displayCredits()
{
  const char *creditStrings[] = {"Created by",
                                 "a GLOBAL team", "at Particle!"};

  messageBoxWithArray(creditStrings, 3, 1);
}

void showKonami()
{
  display.clearDisplay();
  display.display();
  display.setCursor(0, 0);
  display.drawBitmap(0, 0, konamiLogo, 128, 64, 1);
  display.display();
  display.startscrolldiagleft(0x00, 0x07);
}

void showMesh()
{
  display.clearDisplay();
  display.display();
  display.setCursor(0, 0);
  display.drawBitmap(0, 0, meshLogo, 64, 63, 1);
  display.display();
  display.startscrolldiagright(0x00, 0x07);
}
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

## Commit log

2018-05-02 schematic and board v1
    [PartiBadge.brd, PartiBadge.sch]
2018-05-02 tweak layout for smaller badge
    [PartiBadge.sch]
2018-05-02 increase text and add clr on piezo
    [PartiBadge.brd, PartiBadge.sch]
2018-05-02 added tft mounting holes
    [PartiBadge.brd]
2018-05-03 added frame and cleaned up schematic; added 5-way joystick
    [PartiBadge.brd, PartiBadge.sch]
2018-05-03 routed board. closes #3 and #4
    [PartiBadge.brd]
2018-05-04 added slot for lipo and antenna; closes #7
    [PartiBadge.brd]
2018-05-04 Add clr to 3v3 line next to switch; closes #9; add text to back; closes #8
    [PartiBadge.brd, PartiBadge.sch]
2018-05-04 fix schematic and board with clr
    [PartiBadge.brd, PartiBadge.sch]
2018-05-04 cleaning up routes
    [PartiBadge.brd]
2018-05-04 route and via cleanup; closes #11
    [PartiBadge.brd]
2018-05-04 rear-side logo positioning
    [PartiBadge.brd]
2018-05-04 fix right-angle routes; closes #13
    [PartiBadge.brd]
2018-05-04 added ground plane to top; closes #16
    [PartiBadge.brd]
2018-05-04 increase size of slot; closes #15
    [PartiBadge.brd]
2018-05-04 smash ref designators and clean up refs; closes #14
    [PartiBadge.brd, PartiBadge.sch]
2018-05-04 added A, B, C, D to silk; closes #17
    [PartiBadge.brd]
2018-05-04 move the spark logo
    [PartiBadge.brd]
2018-05-04 tented vias; closes #19
    [PartiBadge.brd]
2018-05-04 re-tented the accidentally untented vias
    [PartiBadge.brd]
2018-05-04 generated gerbers
    [PartiBadge.brd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]
2018-05-07 final updates for fabrication
    [PartiBadge.brd, PartiBadge.sch]
2018-05-08 wired up switch to toggle between display and game mode; closes #35
2018-05-09 wired up piezo buzzer; closes #39
2018-05-09 bodge Piezo by shorting C0 to WKP/A7 until #40 can be addressed
    [parti-badge.h]
2018-05-10 working on temp sensor
2018-05-10 added device cloud variables for temp and hunmidity; closes #33
2018-05-10 check battery every five min; closes #45
2018-05-10 implement piezo buzz and shutoff when battery is critical; closes #28
    [parti-badge.h]
2018-05-11 wired up tft and added startup text; closes #43
2018-05-11 wired up LED buttons; closes #42
2018-05-11 show temp and hu when A button is pressed; closes #31
2018-05-11 show battery % when B is pressed; closes #30
2018-05-14 wired up tactile switch; closes #47. started to organize loop around modes
2018-05-16 wired up sd; closes #49
2018-05-18 finish secret feature support
    [PartiBadge.sch]
2018-05-23 moved piezo pin in schematic; closes #41
    [PartiBadge-1.1.brd, PartiBadge-1.1.sch, PartiBadge.brd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]
2018-05-23 moved tft cs pin; closes #50
    [PartiBadge-1.1.brd, PartiBadge-1.1.sch]
2018-05-23 rev partibadge hardware for ndc oslo
    [PartiBadge-1.1.brd, PartiBadge-1.1.sch]
2018-06-04 updated schematic and board
    [PartiBadge-1.1.brd, PartiBadge-1.1.sch]
2018-06-13 added badge v2 design
    [PartiBadge-v2.brd, PartiBadge-v2.sch]
2018-06-17 revisions to brd v2
    [PartiBadge-1.1.brd, PartiBadge-v2.brd, PartiBadge-v2.sch]
2018-06-19 final update before initial fab run
    [PartiBadge-v2.brd]
2018-06-20 fixed power routing and made 3V3 traces wider
    [PartiBadge-v2.brd, PartiBadge-v2.sch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]
2018-06-20 widened traces from batt to converter
    [PartiBadge-v2.brd, PartiBadge-v2.sch]
2018-06-20 removed gerbers
    [copper_bottom.gbr, copper_top.gbr, drills.xln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]
2018-06-29 fix v2 board issues
    [PartiBadge-v2.brd, PartiBadge-v2.sch]
2018-07-01 mode switch to power and other cosmetic changes
    [PartiBadge-v2.brd, PartiBadge-v2.sch]
2018-07-01 added board stackup and cosmetic fixes
    [PartiBadge-v2.brd]
2018-07-02 updated schematic and layout based on feedback from Brett
    [PartiBadge-v2.brd, PartiBadge-v2.sch]
2018-07-02 additional layout tweaks
    [PartiBadge-v2.brd, PartiBadge-v2.sch]
2018-07-02 added vias for ground plane
    [PartiBadge-v2.brd]
2018-07-02 fix D7 breakout placement
    [PartiBadge-v2.brd, PartiBadge-v2.sch]
2018-07-02 added BOM
    [PartiBadgeBOM.xlsx]
2018-07-03 added v2 gerbers
    [copper_bottom_l4.gbr, copper_top_l1.gbr, drills.xln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]
2018-07-13 implement mode switch with buttons, fixed simon-says; closes #71; closes #68
    [parti-badge.h]
2018-08-02 remove serial prints
2018-08-23 added Xenon-based v3 design
    [PartiBadge-v2.sch, PartiBadge-v3.brd, PartiBadge-v3.sch]
2018-08-23 swapped out npn transistor
    [PartiBadge-v3.brd, PartiBadge-v3.sch]
2018-08-23 added transistor to layout
    [PartiBadge-v3.brd]
2018-08-24 finished Xenon port
    [PartiBadge-1.1.brd, PartiBadge-v3.brd, PartiBadge-v3.sch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]
2018-08-27 piezo tweak from Frank
    [PartiBadge-v3.brd, PartiBadge-v3.sch]
2018-09-06 finalized v3 design
    [PartiBadge-v3.brd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]
2018-09-06 tweak text
    [PartiBadge-v3.brd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]
2018-09-07 regenerate gerbers
    [copper_bottom_l4.gbr, copper_inner_l2.gbr, copper_inner_l3.gbr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]
2018-09-11 fixed temp/hu display for two-color screen
    [mainmenu.h]
2018-09-18 refactored out sensors code
2018-09-19 add pwm fade for LEDs
2018-09-19 fix scrolling of konami logo; closes #131
    [display.cpp]
2018-09-20 change pin-mapping for xenon
2018-09-20 added pulsing led animation; Closes #135
2018-09-25 added battery status; closes #126
2018-09-26 Started implementing hello ping. Fixed buttons; closes #152
    [inputs.cpp, macros.h, parti-badge.cpp]
2018-09-26 added Red and Green button interrupts back; closes #155
2018-09-27 added battery image to screen; for #154
2018-09-27 add logic to turn on buttons when pressed; for #143
2018-09-27 remove button light state
2018-09-27 implemented battery graphic; closes #154
2018-09-28 tweaking button interactions for #143
2018-09-29 turn on buttons when pressed; closes #143
2018-09-29 added LED animations during music menu plays; closes #128

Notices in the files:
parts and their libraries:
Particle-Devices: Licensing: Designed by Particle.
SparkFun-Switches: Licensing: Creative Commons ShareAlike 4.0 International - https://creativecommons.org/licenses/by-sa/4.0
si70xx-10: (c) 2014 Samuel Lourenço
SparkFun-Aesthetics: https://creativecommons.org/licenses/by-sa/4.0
